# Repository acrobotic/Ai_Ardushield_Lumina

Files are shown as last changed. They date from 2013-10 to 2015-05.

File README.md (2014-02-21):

Overview
---
This repository includes the Eagle design files (schematics and layout) for our
[WS2812B RGB LED Shield for the Arduino Uno][1]. The shield design is based on the
popular WS2812 'smart' LED package, which contains an embedded, costant-current
LED driver (the WS2811).

The shield includes **40 WS2812B LEDs in a 5x8 array configuration**. But, contrary to a traditional
LED matrix, the shield uses a single data line (Digital Pin 8) from the 
Arduino to control brightness and color!  The shield also includes a power 
terminal for using an external supply.

The firmware files along with code samples are also included in this
repository.

Product page
---
Please consider buying products from Acrobotic to help fund future Open-Source
projects like this! We'll always put our best effort in every project, and
release all our design files and code for you to use.

[Tutorials, technical details, and more information about this product can be
found here: http://acrobotic.com/catalog/product/view/id/69][1]

On our store, we also [carry a 10-pack][2] of WS2812B RGB LEDs for you to use 
on your next project!

License Information
---

All contents of this repository are licensed under a [Creative Commons
Attribution-ShareAlike 3.0 Unported
License](http://creativecommons.org/licenses/by-sa/3.0/).



[1]: http://acrobotic.com/catalog/product/view/id/69 "Ardushield Lumina"
[2]: http://acrobotic.com/catalog/product/view/id/45 "WS2812B RGB LED - 10-Pack"

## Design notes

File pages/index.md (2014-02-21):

---
layout: page
title: Ai Ardushield Lumina
tagline: Board design files and example firmware for the Acrobotic WS2812B RGB LED Shield (Arduino Uno).
github_project: Ai_Ardushield_Lumina
github_user_url: https://github.com/acrobotic
---
{% include JB/setup %}
{% include INCLUDE.md %}

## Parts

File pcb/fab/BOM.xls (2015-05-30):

Ai Ardushield Lumina – BOM
Cisco Zabala (x1sc0@acrobotic.com) last updated: 26.05.2015
Manufacturer | Manuf. Part Number | Vendor | Vendor Part Number | Type | Designator | Qty | Description | Case | SMD, BGA, LCC, OR TH | Notes
TDK | C0603X5R1A104K030BC | Digi-Key | 445-1324-1-ND | Capacitors | C1..C40 | 40 | CAP CER 0.1UF 50V Y5V 0603 | 0603 | SMD
WorldSemi | WS2812B | Acrobotic | LED-00003 | LEDs | LED1..LED40 | 40 | Intelligent control LED | SMD | SMD | CONSIGNED
TE Connectivity | 2-1437565-9 | Digi-Key | 450-1792-1-ND | Buttons | RESET | 1 | SWITCH TACTILE SPST-NO 0.05A 12V | 6mm x 6mm | SMD
 |  | Acrobotic | CON-00007 | Connectors | J1 | 1 | 2-Pin Screw Terminal Block (3.5mm) |  | TH | DNI
 |  | - | - |  | J2 | - | - | - | - | DNI
 |  | Acrobotic | CON-00009 |  | J3, J4, J5, J6, JP1 | 1 | 0.1” Pitch, 40-Pin (Male) |  | TH | DNI
 |  | Acrobotic | CON-00008 |  | - | 1 | 2-Pin Jumper |  | - | DNI

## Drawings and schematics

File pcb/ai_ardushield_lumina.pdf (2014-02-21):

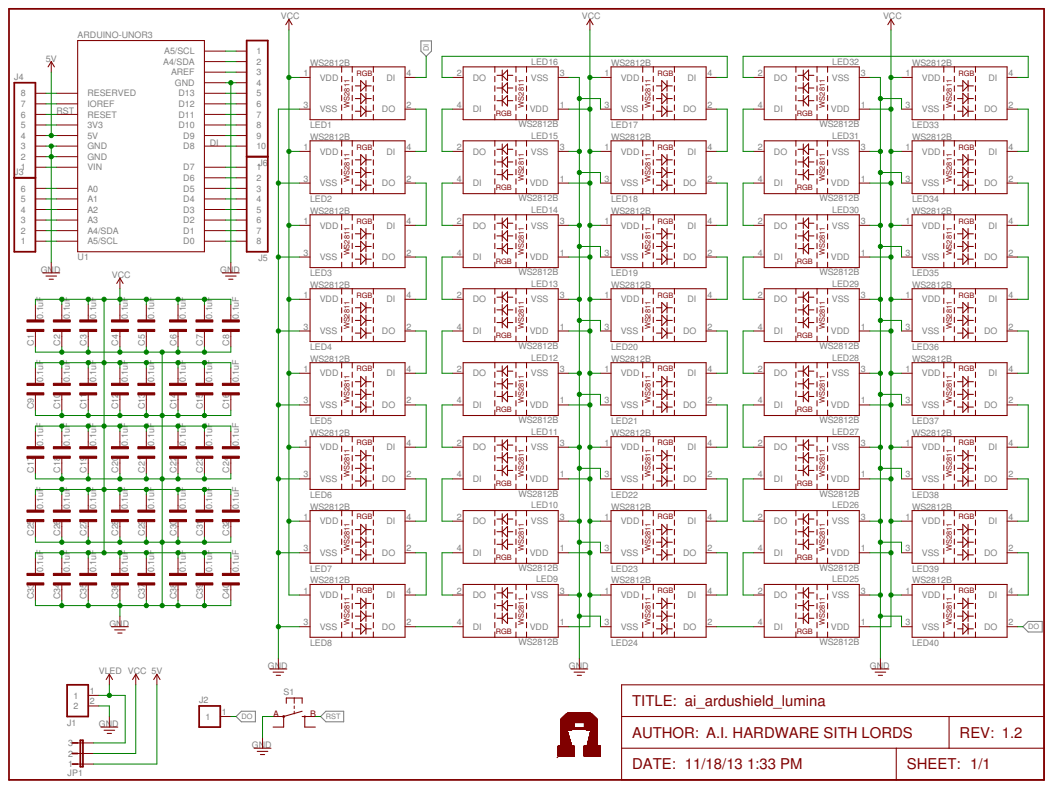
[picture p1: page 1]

RGB WS2811 RGB WS2811 RGB WS2811 RGB WS2811
VDD

1 VSS

LED32

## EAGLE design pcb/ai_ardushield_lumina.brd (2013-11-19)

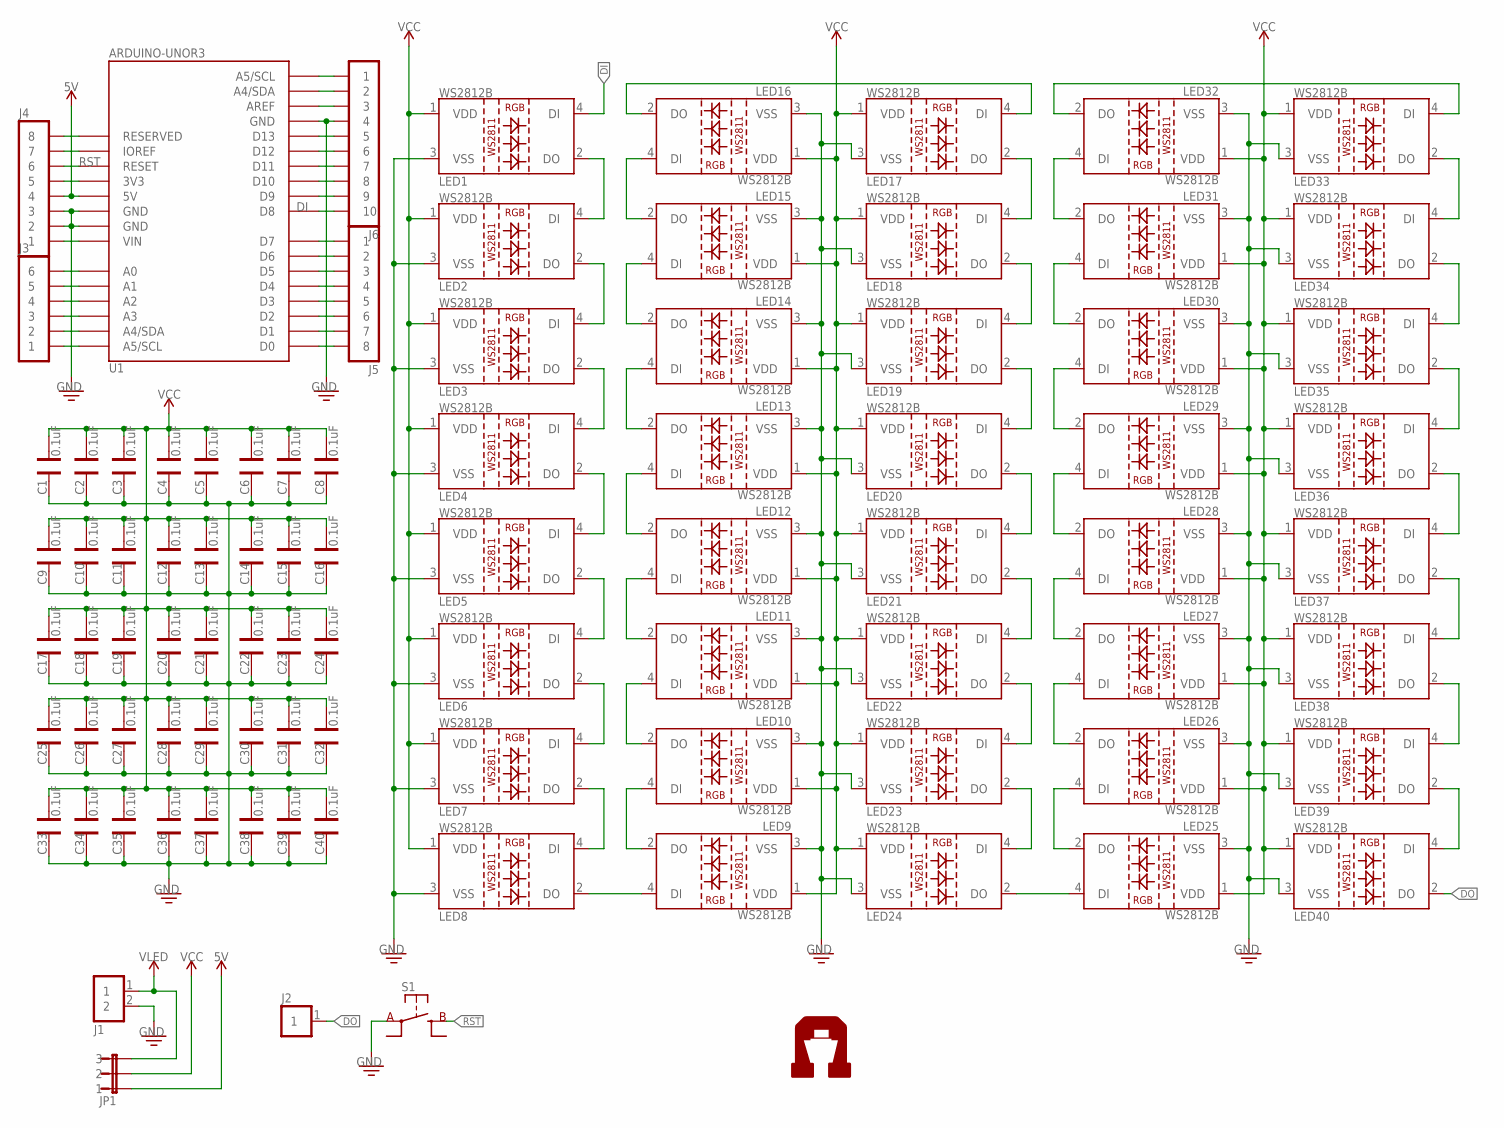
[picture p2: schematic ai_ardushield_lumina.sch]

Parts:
C1, C2, C3, C4, C5, C6, C7, C8, C9, C10, C11, C12, C13, C14, C15, C16, C17, C18, C19, C20, C21, C22, C23, C24, C25, C26, C27, C28, C29, C30, C31, C32, C33, C34, C35, C36, C37, C38, C39, C40: 0.1uF; CAP-0603
J1: 1X02ST; 1X02-ST
J2: 1X01
J3: 1X06
J4, J5: 1X08
J6: 1X10
JP1: 1X03-PJ; 1X03
LED1, LED2, LED3, LED4, LED5, LED6, LED7, LED8, LED9, LED10, LED11, LED12, LED13, LED14, LED15, LED16, LED17, LED18, LED19, LED20, LED21, LED22, LED23, LED24, LED25, LED26, LED27, LED28, LED29, LED30, LED31, LED32, LED33, LED34, LED35, LED36, LED37, LED38, LED39, LED40: LED-WS2812B
S1: SW-SPSTSMD06X06; SW-SPST-SMD06X06
U1: ARDUINOUNOR3-STRAIGHT; UNOR3-STRAIGHT
U$9: AI-LOGOL; AI-LOGO-L

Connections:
5V: J4.4, JP1.1, U1.5V
DI: J6.10, LED1.4 (DI), U1.D8
DO: J2.1, LED40.2 (DO)
GND: C1.2, C2.2, C3.2, C4.2, C5.2, C6.2, C7.2, C8.2, C9.2, C10.2, C11.2, C12.2, C13.2, C14.2, C15.2, C16.2, C17.2, C18.2, C19.2, C20.2, C21.2, C22.2, C23.2, C24.2, C25.2, C26.2, C27.2, C28.2, C29.2, C30.2, C31.2, C32.2, C33.2, C34.2, C35.2, C36.2, C37.2, C38.2, C39.2, C40.2, J1.2, J4.2, J4.3, J6.4, LED1.3 (VSS), LED2.3 (VSS), LED3.3 (VSS), LED4.3 (VSS), LED5.3 (VSS), LED6.3 (VSS), LED7.3 (VSS), LED8.3 (VSS), LED9.3 (VSS), LED10.3 (VSS), LED11.3 (VSS), LED12.3 (VSS), LED13.3 (VSS), LED14.3 (VSS), LED15.3 (VSS), LED16.3 (VSS), LED17.3 (VSS), LED18.3 (VSS), LED19.3 (VSS), LED20.3 (VSS), LED21.3 (VSS), LED22.3 (VSS), LED23.3 (VSS), LED24.3 (VSS), LED25.3 (VSS), LED26.3 (VSS), LED27.3 (VSS), LED28.3 (VSS), LED29.3 (VSS), LED30.3 (VSS), LED31.3 (VSS), LED32.3 (VSS), LED33.3 (VSS), LED34.3 (VSS), LED35.3 (VSS), LED36.3 (VSS), LED37.3 (VSS), LED38.3 (VSS), LED39.3 (VSS), LED40.3 (VSS), S1.A@1 (A), S1.A@2 (A), U1.GND@1 (GND), U1.GND@2 (GND), U1.GND@3 (GND)
unnamed: LED1.2 (DO), LED2.4 (DI)
unnamed: LED2.2 (DO), LED3.4 (DI)
unnamed: LED3.2 (DO), LED4.4 (DI)
unnamed: LED4.2 (DO), LED5.4 (DI)
unnamed: LED5.2 (DO), LED6.4 (DI)
unnamed: LED6.2 (DO), LED7.4 (DI)
unnamed: LED7.2 (DO), LED8.4 (DI)
unnamed: LED8.2 (DO), LED9.4 (DI)
unnamed: LED9.2 (DO), LED10.4 (DI)
unnamed: LED10.2 (DO), LED11.4 (DI)
unnamed: LED11.2 (DO), LED12.4 (DI)
unnamed: LED12.2 (DO), LED13.4 (DI)
unnamed: LED13.2 (DO), LED14.4 (DI)
unnamed: LED14.2 (DO), LED15.4 (DI)
unnamed: LED15.2 (DO), LED16.4 (DI)
unnamed: LED16.2 (DO), LED17.4 (DI)
unnamed: LED17.2 (DO), LED18.4 (DI)
unnamed: LED18.2 (DO), LED19.4 (DI)
unnamed: LED19.2 (DO), LED20.4 (DI)
unnamed: LED20.2 (DO), LED21.4 (DI)
unnamed: LED21.2 (DO), LED22.4 (DI)
unnamed: LED22.2 (DO), LED23.4 (DI)
unnamed: LED23.2 (DO), LED24.4 (DI)
unnamed: LED24.2 (DO), LED25.4 (DI)
unnamed: LED25.2 (DO), LED26.4 (DI)
unnamed: LED26.2 (DO), LED27.4 (DI)
unnamed: LED27.2 (DO), LED28.4 (DI)
unnamed: LED28.2 (DO), LED29.4 (DI)
unnamed: LED29.2 (DO), LED30.4 (DI)
unnamed: LED30.2 (DO), LED31.4 (DI)
unnamed: LED31.2 (DO), LED32.4 (DI)
unnamed: LED32.2 (DO), LED33.4 (DI)
unnamed: LED33.2 (DO), LED34.4 (DI)
unnamed: LED34.2 (DO), LED35.4 (DI)
unnamed: LED35.2 (DO), LED36.4 (DI)
unnamed: LED36.2 (DO), LED37.4 (DI)
unnamed: J4.8, U1.RESERVED
unnamed: J4.7, U1.IOREF
unnamed: J4.5, U1.3V3
unnamed: J4.1, U1.VIN
unnamed: J3.6, U1.A0
unnamed: J3.5, U1.A1
unnamed: J3.4, U1.A2
unnamed: J3.3, U1.A3
unnamed: J3.2, U1.A4/SDA@1 (A4/SDA)
unnamed: J3.1, U1.A5/SCL@1 (A5/SCL)
unnamed: J5.8, U1.D0
unnamed: J5.7, U1.D1
unnamed: J5.6, U1.D2
unnamed: J5.5, U1.D3
unnamed: J5.4, U1.D4
unnamed: J5.3, U1.D5
unnamed: J6.1, U1.A5/SCL@2 (A5/SCL)
unnamed: J6.2, U1.A4/SDA@2 (A4/SDA)
unnamed: J6.3, U1.AREF
unnamed: J6.5, U1.D13
unnamed: J6.6, U1.D12
unnamed: J6.7, U1.D11
unnamed: J6.8, U1.D10
unnamed: J6.9, U1.D9
unnamed: J5.1, U1.D7
unnamed: J5.2, U1.D6
unnamed: LED37.2 (DO), LED38.4 (DI)
unnamed: LED38.2 (DO), LED39.4 (DI)
unnamed: LED39.2 (DO), LED40.4 (DI)
RST: J4.6, S1.B@1 (B), S1.B@2 (B), U1.RESET
VCC: C1.1, C2.1, C3.1, C4.1, C5.1, C6.1, C7.1, C8.1, C9.1, C10.1, C11.1, C12.1, C13.1, C14.1, C15.1, C16.1, C17.1, C18.1, C19.1, C20.1, C21.1, C22.1, C23.1, C24.1, C25.1, C26.1, C27.1, C28.1, C29.1, C30.1, C31.1, C32.1, C33.1, C34.1, C35.1, C36.1, C37.1, C38.1, C39.1, C40.1, JP1.2, LED1.1 (VDD), LED2.1 (VDD), LED3.1 (VDD), LED4.1 (VDD), LED5.1 (VDD), LED6.1 (VDD), LED7.1 (VDD), LED8.1 (VDD), LED9.1 (VDD), LED10.1 (VDD), LED11.1 (VDD), LED12.1 (VDD), LED13.1 (VDD), LED14.1 (VDD), LED15.1 (VDD), LED16.1 (VDD), LED17.1 (VDD), LED18.1 (VDD), LED19.1 (VDD), LED20.1 (VDD), LED21.1 (VDD), LED22.1 (VDD), LED23.1 (VDD), LED24.1 (VDD), LED25.1 (VDD), LED26.1 (VDD), LED27.1 (VDD), LED28.1 (VDD), LED29.1 (VDD), LED30.1 (VDD), LED31.1 (VDD), LED32.1 (VDD), LED33.1 (VDD), LED34.1 (VDD), LED35.1 (VDD), LED36.1 (VDD), LED37.1 (VDD), LED38.1 (VDD), LED39.1 (VDD), LED40.1 (VDD)
VLED: J1.1, JP1.3

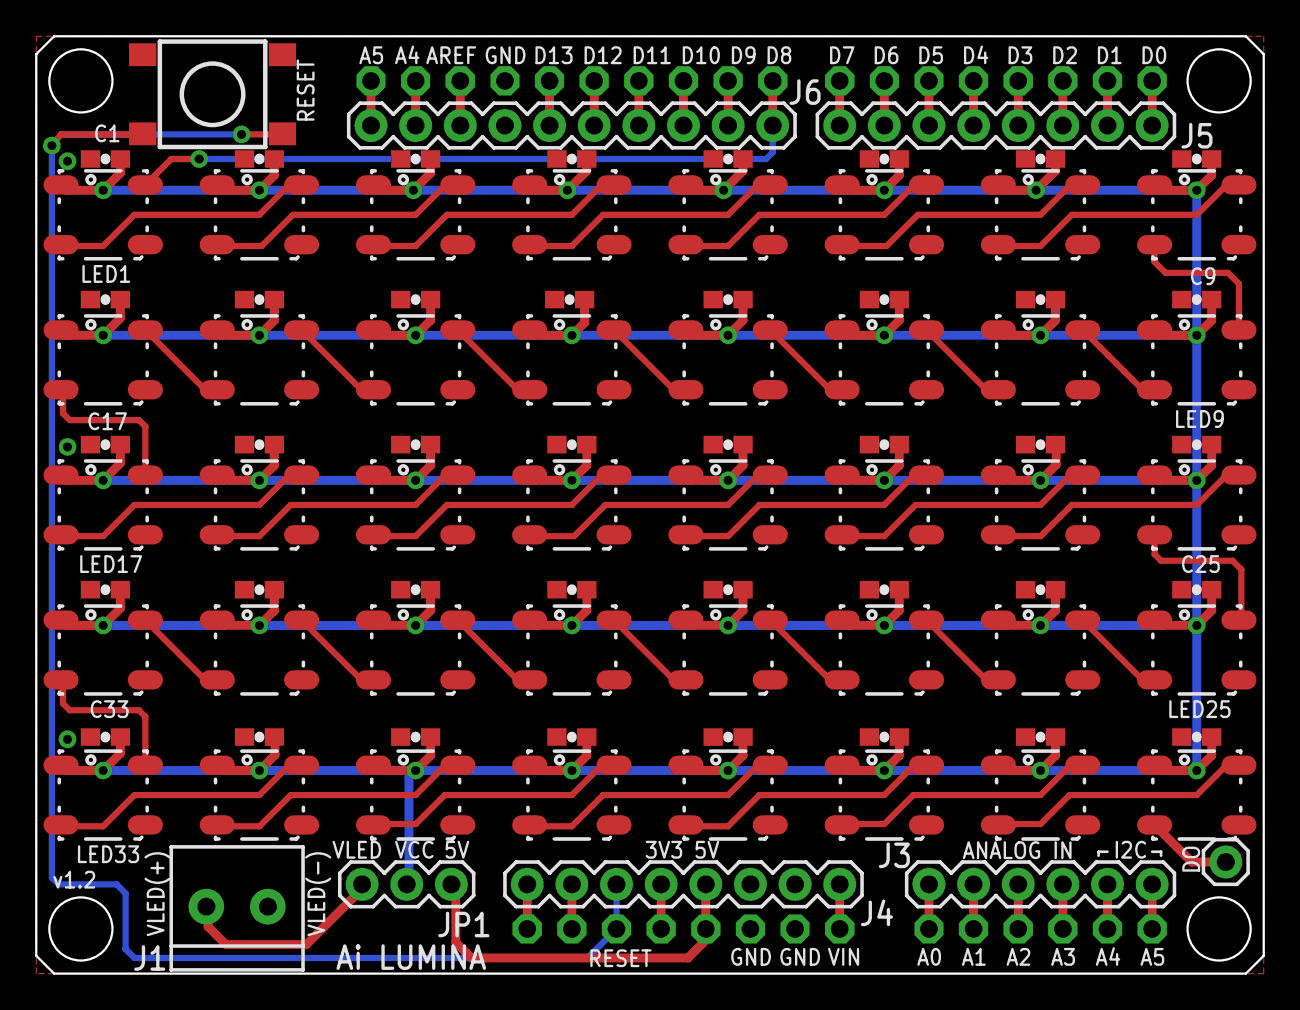
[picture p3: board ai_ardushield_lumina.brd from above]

Board: 2 copper layers, 69.8 x 53.3 mm, 90 parts (1 on the bottom side), 72 nets.

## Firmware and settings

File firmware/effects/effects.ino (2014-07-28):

#include "Ai_WS2811.h"

#define NUM_PIXELS 40
#define DATA_PIN 8

Ai_WS2811 ws2811;

struct CRGB {
  unsigned char g;
  unsigned char r;
  unsigned char b;
} *leds;

//some initial values
void setup()
{
  ws2811.init(DATA_PIN,NUM_PIXELS);
  leds = (struct CRGB*)ws2811.getRGBData();
}

void loop(){
  rainbow();
}

/**
 * Color climb function
 **/
void rainbow(){
  while(1) {
    for(int i = 255; i >= 0; i--)
    {
      int val = i;
      for (int led = 0; led < NUM_PIXELS; led++) {
          val = (val + 255/NUM_PIXELS) % 255;
          setHue(val, led);
      }
      ws2811.sendLedData();
      delay(100);
    }
  }
}

/**
 * HVS to RGB comversion (simplified to the range 0-255)
 **/
void setHue(int h, uint8_t n) {
  //this is the algorithm to convert from RGB to HSV
  double r=0; 
  double g=0; 
  double b=0;

  double hf=h/42.5; // Not /60 as range is _not_ 0-360

  int i=(int)floor(h/42.5);
  double f = h/42.5 - i;
  double qv = 1 - f;
  double tv = f;

  switch (i)
  {
  case 0: 
    r = 1;
    g = tv;
    break;
  case 1: 
    r = qv;
    g = 1;
    break;
  case 2: 
    g = 1;
    b = tv;
    break;
  case 3: 
    g = qv;
    b = 1;
    break;
  case 4:
    r = tv;
    b = 1;
    break;
  case 5: 
    r = 1;
    b = qv;
    break;
  }

  leds[n].r = constrain((int)255*r,0,255);
  leds[n].g = constrain((int)255*g,0,255);
  leds[n].b = constrain((int)255*b,0,255);
}

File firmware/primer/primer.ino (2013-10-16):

/*------------------------------------------------------------------------
  WS2811 demo
------------------------------------------------------------------------*/
#include "Ai_WS2811.h"

#define DATA_PIN 8
#define NUM_LEDS 1

Ai_WS2811 ws2811;

void sendLEDs()
{
  cli();
  for (byte i=0; i<NUM_LEDS; ++i) {
    ws2811.send();
  }
  sei();
}

void setup()
{
  ws2811.init(DATA_PIN);
}

byte a = 0x00;
byte b = 0xff;

void loop()
{
  // Toggles LED between Blue, Green, Read
  ws2811.setColor(a,a,b);
  sendLEDs();
  _delay_ms(1000);
  
  ws2811.setColor(a,b,a);
  sendLEDs();
  _delay_ms(1000);
  
  ws2811.setColor(b,a,a);
  sendLEDs();
  _delay_ms(1000);
}

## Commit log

2013-09-25 first commit.
    [ai_ardushield_lumina.brd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]
2013-10-16 Updated to latest libraries. New Gerbers.
    [ai_ardushield_lumina.brd, ai_ardushield_lumina.sch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]
2013-10-16 Fixed a typo in README.md. Added .pdf file for schematic.
    [ai_ardushield_lumina.sch]
2013-10-25 Modified the routing quite a bit.
    [ai_ardushield_lumina.brd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]
2013-10-25 adding BOM.
    [BOM.xls]
2013-11-19 Changed design to use WS2812Bs
    [ai_ardushield_lumina.brd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]
2015-05-30 adding pnp files
    [BOM.xls]
